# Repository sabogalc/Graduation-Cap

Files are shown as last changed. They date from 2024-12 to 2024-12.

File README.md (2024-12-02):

# Graduation Cap
This is a PCB that I made to sit on top of my graduation cap for my bachelor's in electrical engineering. The board is designed around the 9.5x9.5" Herff Jones caps used at UF, but it could easily be adapted for other caps. This board is capable of playing three different `.WAV` music files, and I have populated mine with three Florida Gators fight songs. There is also an LED sequence that cycles through each light on the cap while displaying a message on the OLED display.

> Graduation Cap
> Side-by-side of the PCB render in KiCad and the board on my cap in real life.

# Project Inspirations

While I have had this project on my mind for a few years now, there are some people that have made similar projects, and I modeled some of my work off of theirs.

1. [LED Graduation Cap](https://github.com/matthewScohen/LED_Graduation_Cap) by Matthew Cohen

2. [Graduation Cap](https://github.com/miekush/graduation-cap) by Mike Kushnerik

Notably, Mike's project has accommodations for the tassel, which I overlooked and ended up just hot gluing onto my cap. The PCB itself is also hot glued at each of the cap's four corners.

# Code

The program to run this board is included in this repository as `main.py`, and it was designed around a Raspberry Pi Pico running MicroPython (yes, I know C would have run better, no I am not good at writing code). You will need the following driver files saved to the Pico in order for the code to run.

1. [sdcard.py](https://github.com/micropython/micropython-lib/blob/master/micropython/drivers/storage/sdcard/sdcard.py) from [micropython-lib](https://github.com/micropython/micropython-lib)

2. [sh1106.py](https://github.com/raspberrypi/pico-micropython-examples/blob/master/i2c/1106oled/sh1106.py) from [Pico MicroPython Examples](https://github.com/raspberrypi/pico-micropython-examples)

3. [tlc5940.py](https://github.com/sabogalc/tlc5940-micropython/blob/master/tlc5940.py) from [TLC5940 MicroPython Library](https://github.com/oysols/tlc5940-micropython)**

** **Please note that the code does not currently work on the Pico. I have linked to my fork of the driver which does work on the Pico and has been submitted as a pull request.**

4. [wavplayer.py](https://github.com/miketeachman/micropython-i2s-examples/blob/master/examples/wavplayer.py) from [MicroPython I2S Examples](https://github.com/miketeachman/micropython-i2s-examples)

# Ordering Parts

I have included BOMs for both DigiKey and Mouser to obtain the parts for this board, but the Mouser BOM is missing the socket headers since I could not find any on there. The board will still work with the components directly soldered down, but I liked the flexibility the sockets offered, especially while debugging. One component that will be needed to be purchased externally is the I2C OLED, and I got mine [on Amazon](https://www.amazon.com/dp/B07BHHV844).

# Notes

I wanted to have a mode where all the lights could come on at once, but I was unable to accomplish this without prominent flickering. I believe this may be due to differences in the forward voltages of the blue and orange LEDs, as the flicker does not occur when only lighting multiple LEDs of one color (side note, the blue LED was [partially invented at UF](https://www.nobelprize.org/prizes/physics/2014/nakamura/biographical/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.)!). If anyone has more information on this, please feel free to share it.

Another thing to note is that I had to cut a hole in my cap so that the battery leads were accessible, but if you wanted to power the board with a USB cable and a power bank that should work as well.

While the board is personalized to me and my graduation year, it can be modified to any year, school, or person. Of course, most of the fun in making something like this is in designing it yourself, so feel free to use this project in part or in whole to help move your project along.

> Graduation Picture
> Me with my graduation cap outside of UF's New Engineering Building (it's not that new but the name has stuck).

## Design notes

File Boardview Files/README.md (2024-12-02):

# Boardview Files

## What is a Boardview File?

A boardview file is a netlist of all the connections on a PCB with every component laid out exactly as it is in real life. This modern approach provides a more intuitive way to inspect connections and troubleshoot PCBs compared to traditional schematic diagrams.

## How Can I View These Files?

Much like how there are many PCB EDA software programs out there, there are also many board viewing programs. The two that I have used and recommend are listed below:

1. **[OpenBoardView](https://github.com/OpenBoardView/OpenBoardView)**  
   - **License:** MIT  
   - **Description:** An open-source tool for viewing boardview files. It provides essential features for inspecting PCB layouts.

2. **[FlexBV](https://pldaniels.com/flexbv/)**  
   - **License:** Commercial (free version available)  
   - **Description:** A commercial tool with advanced features for viewing and analyzing boardview files. The free version offers most of the basic functionalities.

### Example View

Below is a screenshot of my graduation cap PCB as viewed in FlexBV:

Graduation Cap PCB Boardview

In this view, you can observe the following:
- **Net Highlighting:** The +3V3 net is highlighted in green across the board.
- **Component Table:** A table on the right lists components and their pin numbers associated with +3V3.
- **Designator Information:** The designators, values of resistors and capacitors, and component footprints are all displayed.

### Note on Metadata

The metadata you see (e.g., component values, designators) is stored in the `.obdata` file. As of December 2024, this metadata is viewable only in FlexBV. The `.obdata` format is [open and documented](https://openboarddata.org/), and I would very much like to see the feature added to OpenBoardView.

### How Can I Create Boardview Files for My Own Designs?

All of the boardview files I make for my projects are using [an open-source KiCad plugin](https://github.com/whitequark/kicad-boardview). When I first came across this plugin, it had a few bugs with current versions of KiCad, so I submitted some pull requests and the plugin is back into perfect operating condition. The `.obdata` generation script is currently internal since I made a bit of a mess [submitting that PR](https://github.com/whitequark/kicad-boardview/pull/16), but I am looking to release it eventually.

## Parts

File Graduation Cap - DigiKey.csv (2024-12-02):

Index | Quantity | Part Number | Manufacturer Part Number | Description | Customer Reference | Available | Backorder | Unit Price | Extended Price USD
1 | 4 | 1276-1946-1-ND | CL10B105KP8NNNC | CAP CER 1UF 10V X7R 0603 |  | 4 | 0 | 0.08 | 0.32
2 | 1 | 1276-1009-1-ND | CL10B103KB8NNNC | CAP CER 10000PF 50V X7R 0603 |  | 1 | 0 | 0.08 | 0.08
3 | 3 | P1.00KHCT-ND | ERJ-3EKF1001V | RES SMD 1K OHM 1% 1/10W 0603 |  | 3 | 0 | 0.1 | 0.3
4 | 2 | P2.00KHCT-ND | ERJ-3EKF2001V | RES SMD 2K OHM 1% 1/10W 0603 |  | 2 | 0 | 0.1 | 0.2
5 | 20 | SLI-343D8U3F-ND | SLI-343D8U3F | LED ORANGE DIFFUSED T-1 T/H |  | 20 | 0 | 0.302 | 6.04
6 | 18 | 732-5015-ND | 151051BS04000 | LED BLUE DIFFUSED 5MM ROUND T/H |  | 18 | 0 | 0.24 | 4.32
7 | 1 | 296-35975-1-ND | TLC5940PWPR | IC LED DRVR LIN 120MA 28HTSSOP |  | 1 | 0 | 3 | 3
8 | 1 | MCP73812T-420I/OTCT-ND | MCP73812T-420I/OT | IC BATT CNTL LI-ION 1CEL SOT23-5 |  | 1 | 0 | 0.73 | 0.73
9 | 1 | TC2015-3.3VCTCT-ND | TC2015-3.3VCTTR | IC REG LINEAR 3.3V 100MA SOT23-5 |  | 1 | 0 | 0.56 | 0.56
10 | 4 | CKN10880CT-ND | PTS645SL43SMTR92 LFS | SWITCH TACTILE SPST-NO 0.05A 12V |  | 4 | 0 | 0.4 | 1.6
11 | 3 | IRF9540NSTRLPBFCT-ND | IRF9540NSTRLPBF | MOSFET P-CH 100V 23A D2PAK |  | 3 | 0 | 2.72 | 8.16
12 | 2 | S7018-ND | PPTC201LFBN-RC | CONN HDR 20POS 0.1 TIN PCB |  | 2 | 0 | 1.1 | 2.2
13 | 1 | 2648-SC0917-ND | SC0917 | RASPBERRY PI PICO H RP2040 |  | 1 | 0 | 5 | 5
14 | 1 | S7002-ND | PPTC041LFBN-RC | CONN HDR 4POS 0.1 TIN PCB |  | 1 | 0 | 0.4 | 0.4
15 | 1 | S7005-ND | PPTC071LFBN-RC | CONN HDR 7POS 0.1 TIN PCB |  | 1 | 0 | 0.51 | 0.51
16 | 1 | 1528-1696-ND | 3006 | EVAL BOARD FOR MAX98357A |  | 1 | 0 | 5.95 | 5.95
17 | 1 | 102-1560-ND | CLS0401MAE-L152 | SPEAKER 4OHM 1W TOP PORT 91DB |  | 1 | 0 | 4.58 | 4.58
18 | 1 | S7007-ND | PPTC091LFBN-RC | CONN HDR 9POS 0.1 TIN PCB |  | 1 | 0 | 0.61 | 0.61
19 | 1 | 1528-4682-ND | 4682 | MICROSD SPI/SPIO BREAKOUT BOARD |  | 1 | 0 | 3.5 | 3.5
20 | 1 | 455-1719-ND | S2B-PH-K-S | CONN HEADER R/A 2POS 2MM |  | 1 | 0 | 0.1 | 0.1
21 | 1 | 1528-1838-ND | 258 | BATTERY LITH-ION 3.7V 1.2AH |  | 1 | 0 | 9.95 | 9.95

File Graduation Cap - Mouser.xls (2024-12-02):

SHOPPING CART
This is not an invoice
02-Dec-24 03:36:52
 | Mouser # | Mfr. # | Manufacturer | Customer # | Description | RoHS | Lifecycle | Order Qty. | Price (USD) | Ext.: (USD)
1 | 187-CL10B105KP8NNNC | CL10B105KP8NNNC | Samsung Electro-Mechanics |  | Multilayer Ceramic Capacitors MLCC - SMD/SMT 1uF+/-10% 10V X7R 16 0603 | RoHS Compliant |  | 4 | $0.10 | $0.40
2 | 187-CL10B103KB8NNNC | CL10B103KB8NNNC | Samsung Electro-Mechanics |  | Multilayer Ceramic Capacitors MLCC - SMD/SMT SAMSUNG | RoHS Compliant |  | 1 | $0.10 | $0.10
3 | 667-ERJ-3EKF1001V | ERJ-3EKF1001V | Panasonic |  | Thick Film Resistors - SMD 0603 1Kohms 1% AEC-Q200 | RoHS Compliant By Exemption |  | 3 | $0.10 | $0.30
4 | 667-ERJ-3EKF2001V | ERJ-3EKF2001V | Panasonic |  | Thick Film Resistors - SMD 0603 2Kohms 1% AEC-Q200 | RoHS Compliant By Exemption |  | 2 | $0.10 | $0.20
5 | 755-SLI-343D8U3F | SLI-343D8U3F | ROHM Semiconductor |  | Standard LEDs - Through Hole ORANGE-DIFF COLORED 40 VIEW ANGLE 611NM | RoHS Compliant |  | 20 | $0.299 | $5.98
6 | 710-151051BS04000 | 151051BS04000 | Wurth Elektronik |  | Standard LEDs - Through Hole WL-TMRC THT Mono Diffused Rnd5mm Blue | RoHS Compliant |  | 18 | $0.26 | $4.68
7 | 595-TLC5940PWPR | TLC5940PWPR | Texas Instruments |  | LED Lighting Drivers 4096 Step Grayscale LED Driver | RoHS Compliant |  | 1 | $3.00 | $3.00
8 | 579-MCP73812T-420IOT | MCP73812T-420I/OT | Microchip |  | Battery Management Simple Integr Li-Ion /Li-Poly Chrg | RoHS Compliant |  | 1 | $0.68 | $0.68
9 | 579-TC2015-3.3VCTTR | TC2015-3.3VCTTR | Microchip |  | LDO Voltage Regulators .1mA w/Shtdn & Ref B 3.3V | RoHS Compliant |  | 1 | $0.50 | $0.50
10 | 611-PTS645SL43SMTR92 | PTS645SL43SMTR92LFS | C&K Switches |  | Tactile Switches SWITCH TACTILE | RoHS Compliant | Factory Special Order | 4 | $0.21 | $0.84
11 | 942-IRF9540NSTRLPBF | IRF9540NSTRLPBF | Infineon |  | MOSFETs MOSFT PCh -100V -23A 117mOhm 64.7nC |  |  | 3 | $2.29 | $6.87
12 | 358-SC0917 | SC0917 | Raspberry Pi |  | Single Board Computers Raspberry Pi Pico H | RoHS Compliant |  | 1 | $5.00 | $5.00
13 | 485-3006 | 3006 | Adafruit |  | Amplifier IC Development Tools I2S 3W Class D Amp Breakout MAX98357A | RoHS Compliant |  | 1 | $5.95 | $5.95
14 | 490-CLS0401MAE-L152 | CLS0401MAE-L152 | Same Sky |  | Speakers & Transducers Speakers | RoHS Compliant |  | 1 | $4.12 | $4.12
15 | 485-4682 | 4682 | Adafruit |  | Memory IC Development Tools Adafruit Micro SD SPI or SDIO Card Breakout Board - 3V ONLY! | RoHS Compliant |  | 1 | $3.50 | $3.50
16 | 306-S2BPHKSLFSNPP | S2B-PH-K-S(LF)(SN)(PP) | JST |  | JST Automotive Connectors PH HEADER (SIDE) | RoHS Compliant | New At Mouser | 1 | $0.18 | $0.18
17 | 485-258 | 258 | Adafruit |  | Adafruit Accessories Lithium Ion Polymer Battery 3.7V 1200mAh | RoHS Compliant |  | 1 | $9.95 | $9.95
By submitting your order you agree to these terms and conditions. (https://www.mouser.com/saleterms) |  |  |  |  |  |  |  |  | Merchandise: | $52.25
Prices are reflected at the date and time shown. |  |  |  |  |  |  |  |  | Shipping Charge: | $7.99
 |  |  |  |  |  |  |  |  | Backorder Shipping: | $1.99

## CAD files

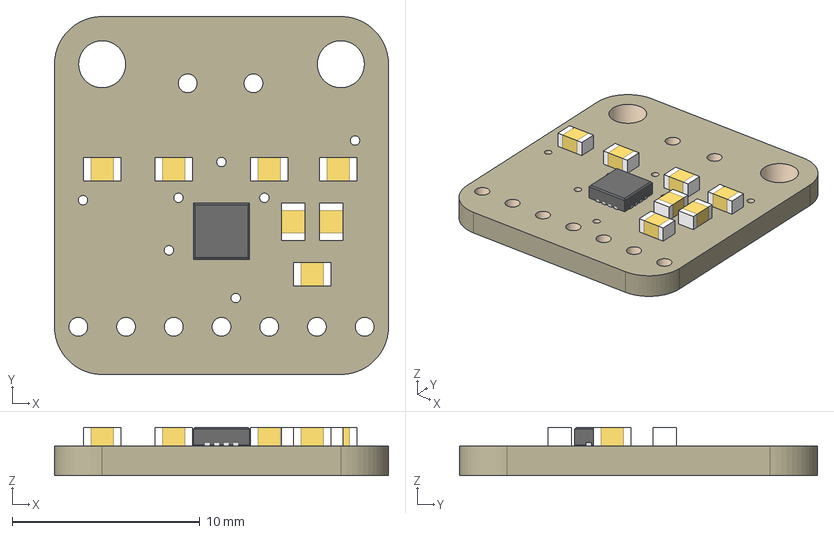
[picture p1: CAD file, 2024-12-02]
STEP Files/3006 MAX98357.step
17.8 x 19.1 x 2.57 mm
Board
MAX98357A
220pF x 7

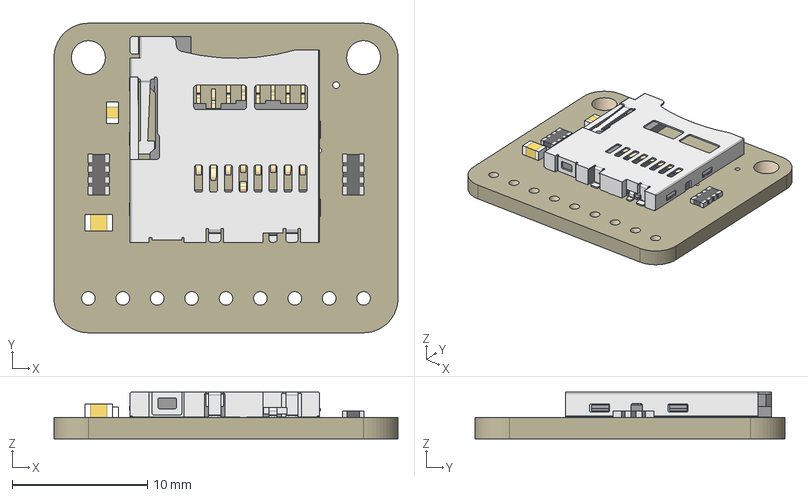
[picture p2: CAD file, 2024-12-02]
STEP Files/4682 Micro SD Breakout.step
25.4 x 22.9 x 3.45 mm
Board
microSD
10uF
0.1uF
47K x 2

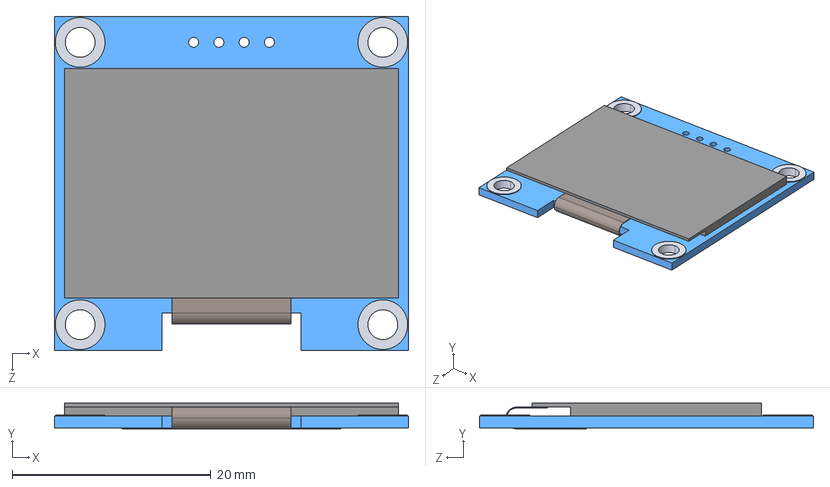
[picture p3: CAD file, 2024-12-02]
STEP Files/I2C SSH1106 OLED.STEP
35.6 x 2.60 x 33.6 mm

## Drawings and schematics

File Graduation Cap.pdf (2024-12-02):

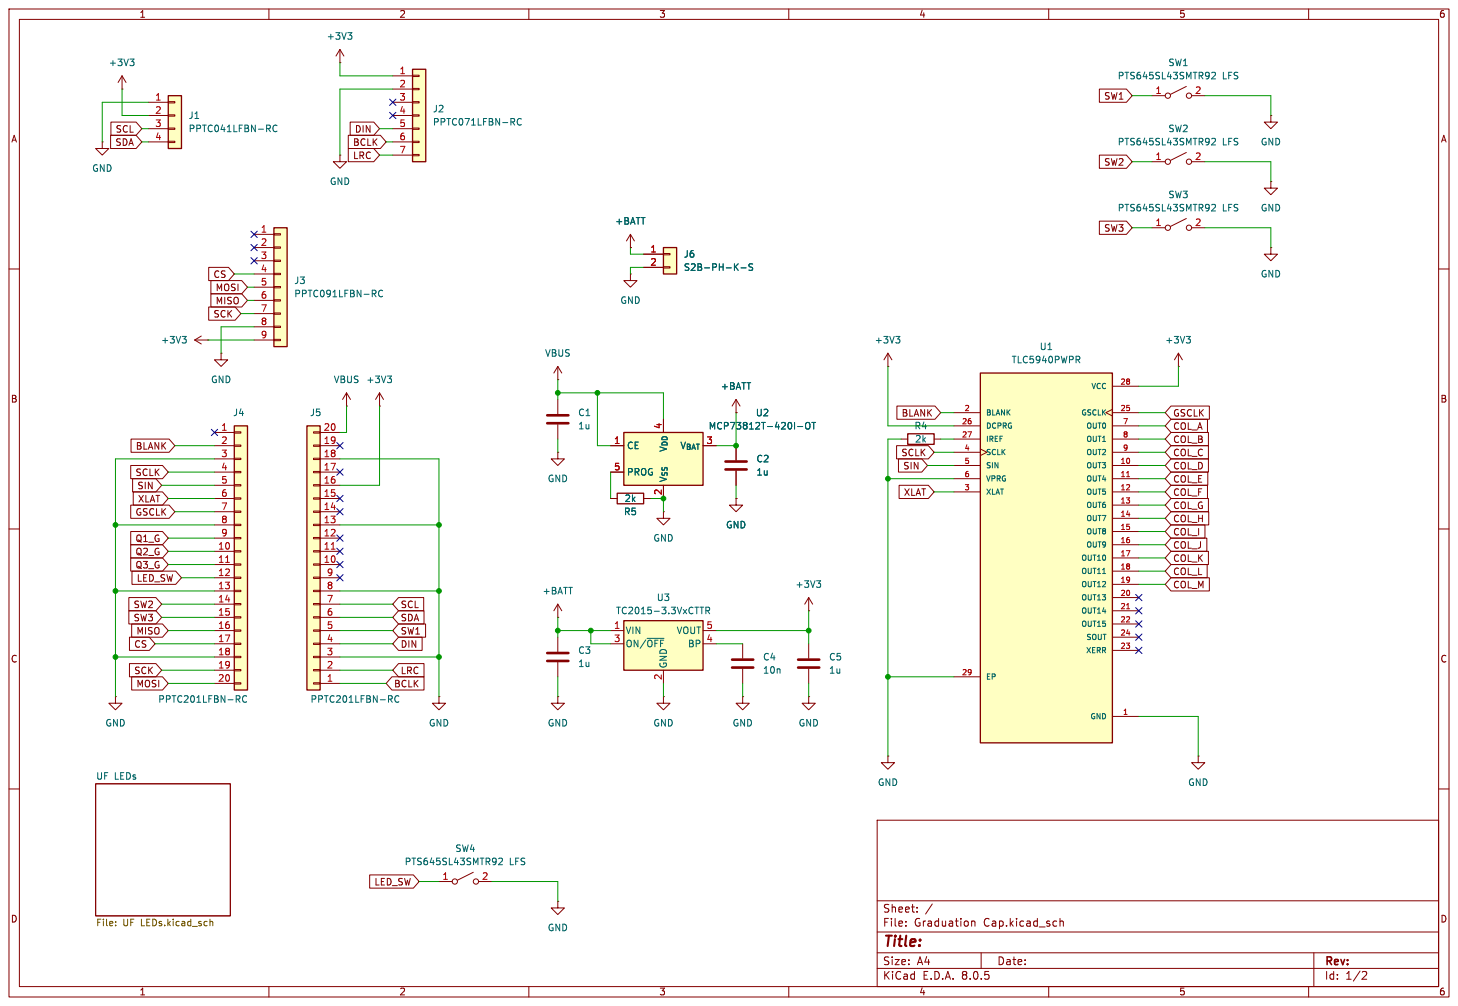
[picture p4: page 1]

2 ON/~{OFF} 3 BP 4 VOUT 5 U3 TC2015-3.3VxCTTR GSCLK MISO

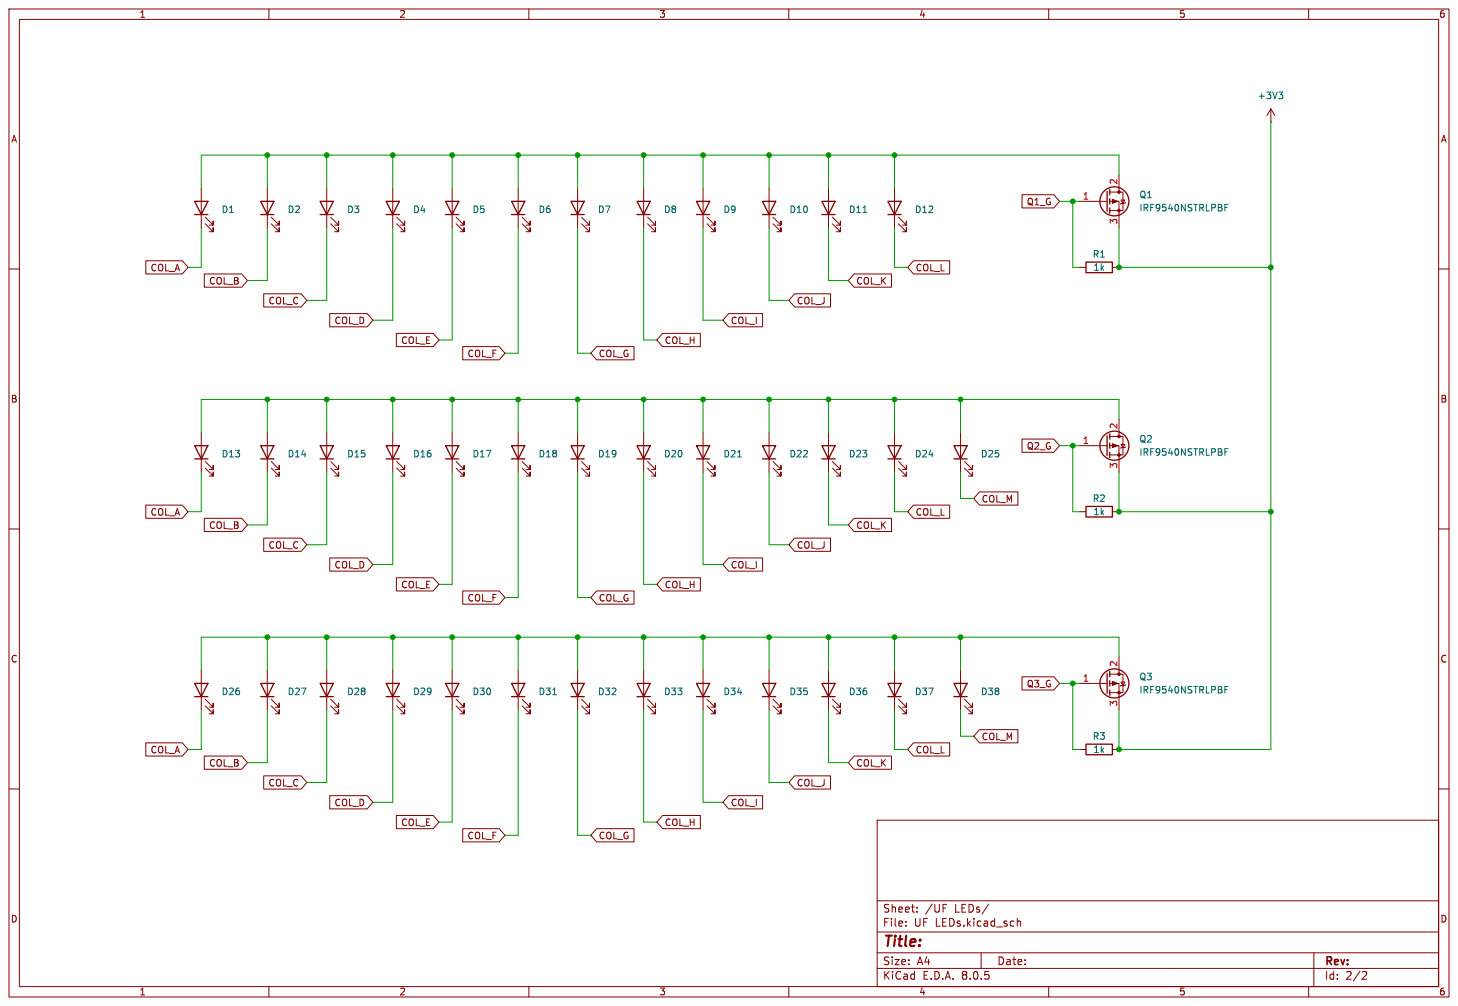
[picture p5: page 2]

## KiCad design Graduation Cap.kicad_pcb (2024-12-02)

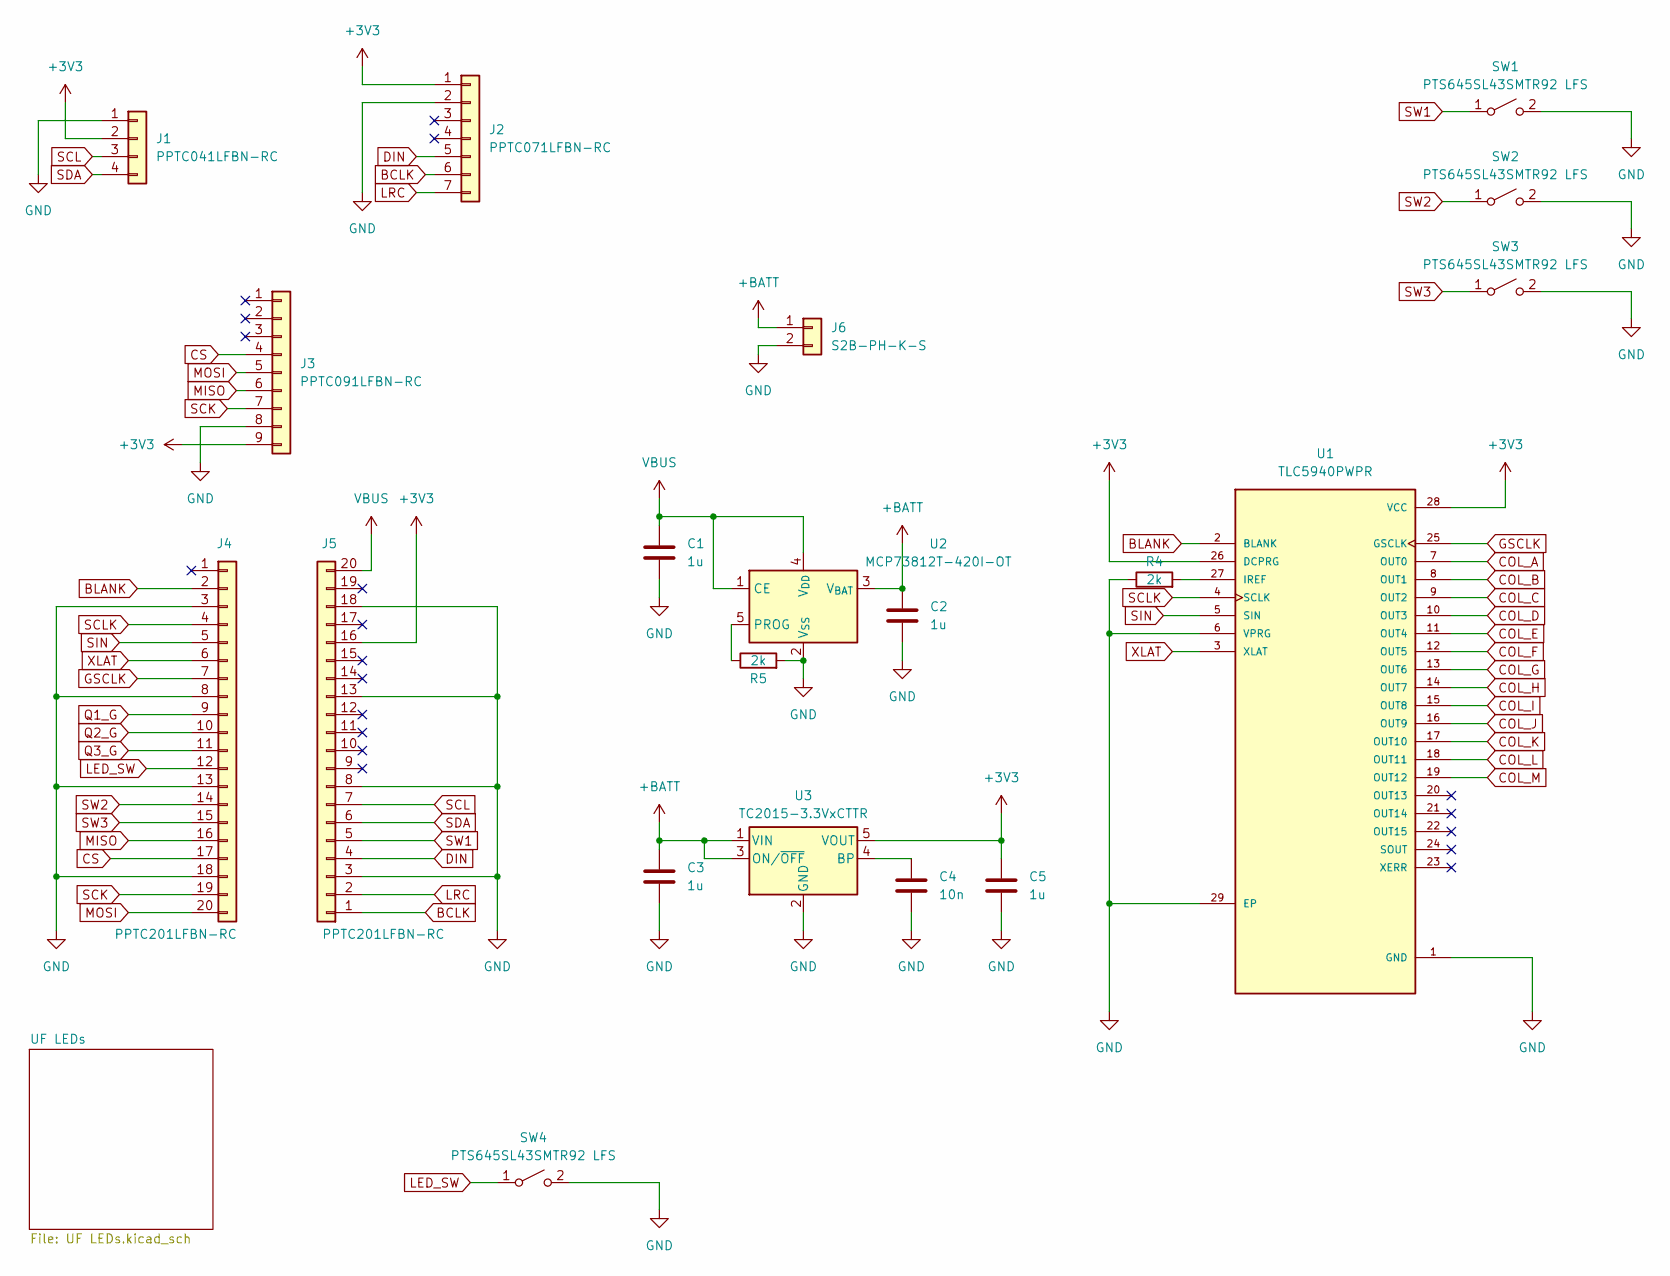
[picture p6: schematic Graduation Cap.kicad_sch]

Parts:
C1, C2, C3, C5: 1u; C_0603_1608Metric
C4: 10n; C_0603_1608Metric
J1: PPTC041LFBN-RC; PinSocket_1x04_P2.54mm_Vertical
J2: PPTC071LFBN-RC; PinSocket_1x07_P2.54mm_Vertical
J3: PPTC091LFBN-RC; PinSocket_1x09_P2.54mm_Vertical
J4, J5: PPTC201LFBN-RC; PinSocket_1x20_P2.54mm_Vertical
J6: S2B-PH-K-S; JST_PH_S2B-PH-K_1x02_P2.00mm_Horizontal
R4, R5: 2k; R_0603_1608Metric
SW1, SW2, SW3, SW4: PTS645SL43SMTR92 LFS; SW_SPST_PTS645
U1: TLC5940PWPR; HTSSOP-28-1EP_4.4x9.7mm_P0.65mm_EP3.4x9.5mm_Mask2.4x6.17mm_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
U2: MCP73812T-420I-OT; SOT-23-5
U3: TC2015-3.3VxCTTR; SOT-23-5

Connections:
+3V3: C5.1, J1.2, J2.1, J3.9, J5.16, U1.26 (DCPRG), U1.28 (VCC), U3.5 (VOUT); also elsewhere on the board
+BATT: C2.1, C3.1, J6.1, U2.3 (V_{BAT}), U3.1 (VIN), U3.3 (ON/~OFF)
BCLK: J2.6, J5.1
BLANK: J4.2, U1.2 (BLANK)
COL_A: U1.7 (OUT0); also elsewhere on the board
COL_B: U1.8 (OUT1); also elsewhere on the board
COL_C: U1.9 (OUT2); also elsewhere on the board
COL_D: U1.10 (OUT3); also elsewhere on the board
COL_E: U1.11 (OUT4); also elsewhere on the board
COL_F: U1.12 (OUT5); also elsewhere on the board
COL_G: U1.13 (OUT6); also elsewhere on the board
COL_H: U1.14 (OUT7); also elsewhere on the board
COL_I: U1.15 (OUT8); also elsewhere on the board
COL_J: U1.16 (OUT9); also elsewhere on the board
COL_K: U1.17 (OUT10); also elsewhere on the board
COL_L: U1.18 (OUT11); also elsewhere on the board
COL_M: U1.19 (OUT12); also elsewhere on the board
CS: J3.4, J4.17
DIN: J2.5, J5.4
GND: C1.2, C2.2, C3.2, C4.2, C5.2, J1.1, J2.2, J3.8, J4.3, J4.8, J4.13, J4.18, J5.3, J5.8, J5.13, J5.18, J6.2, R4.1, R5.2, SW1.2 (B), SW2.2 (B), SW3.2 (B), SW4.2 (B), U1.1 (GND), U1.6 (VPRG), U1.29 (EP), U2.2 (V_{SS}), U3.2 (GND)
GSCLK: J4.7, U1.25 (GSCLK)
LED_SW: J4.12, SW4.1 (A)
LRC: J2.7, J5.2
MISO: J3.6, J4.16
MOSI: J3.5, J4.20
unnamed: R4.2, U1.27 (IREF)
unnamed: R5.1, U2.5 (PROG)
unnamed: C4.1, U3.4 (BP)
Q1_G: J4.9; also elsewhere on the board
Q2_G: J4.10; also elsewhere on the board
Q3_G: J4.11; also elsewhere on the board
SCK: J3.7, J4.19
SCL: J1.3, J5.7
SCLK: J4.4, U1.4 (SCLK)
SDA: J1.4, J5.6
SIN: J4.5, U1.5 (SIN)
SW1: J5.5, SW1.1 (A)
SW2: J4.14, SW2.1 (A)
SW3: J4.15, SW3.1 (A)
VBUS: C1.1, J5.20, U2.1 (CE), U2.4 (V_{DD})
XLAT: J4.6, U1.3 (XLAT)

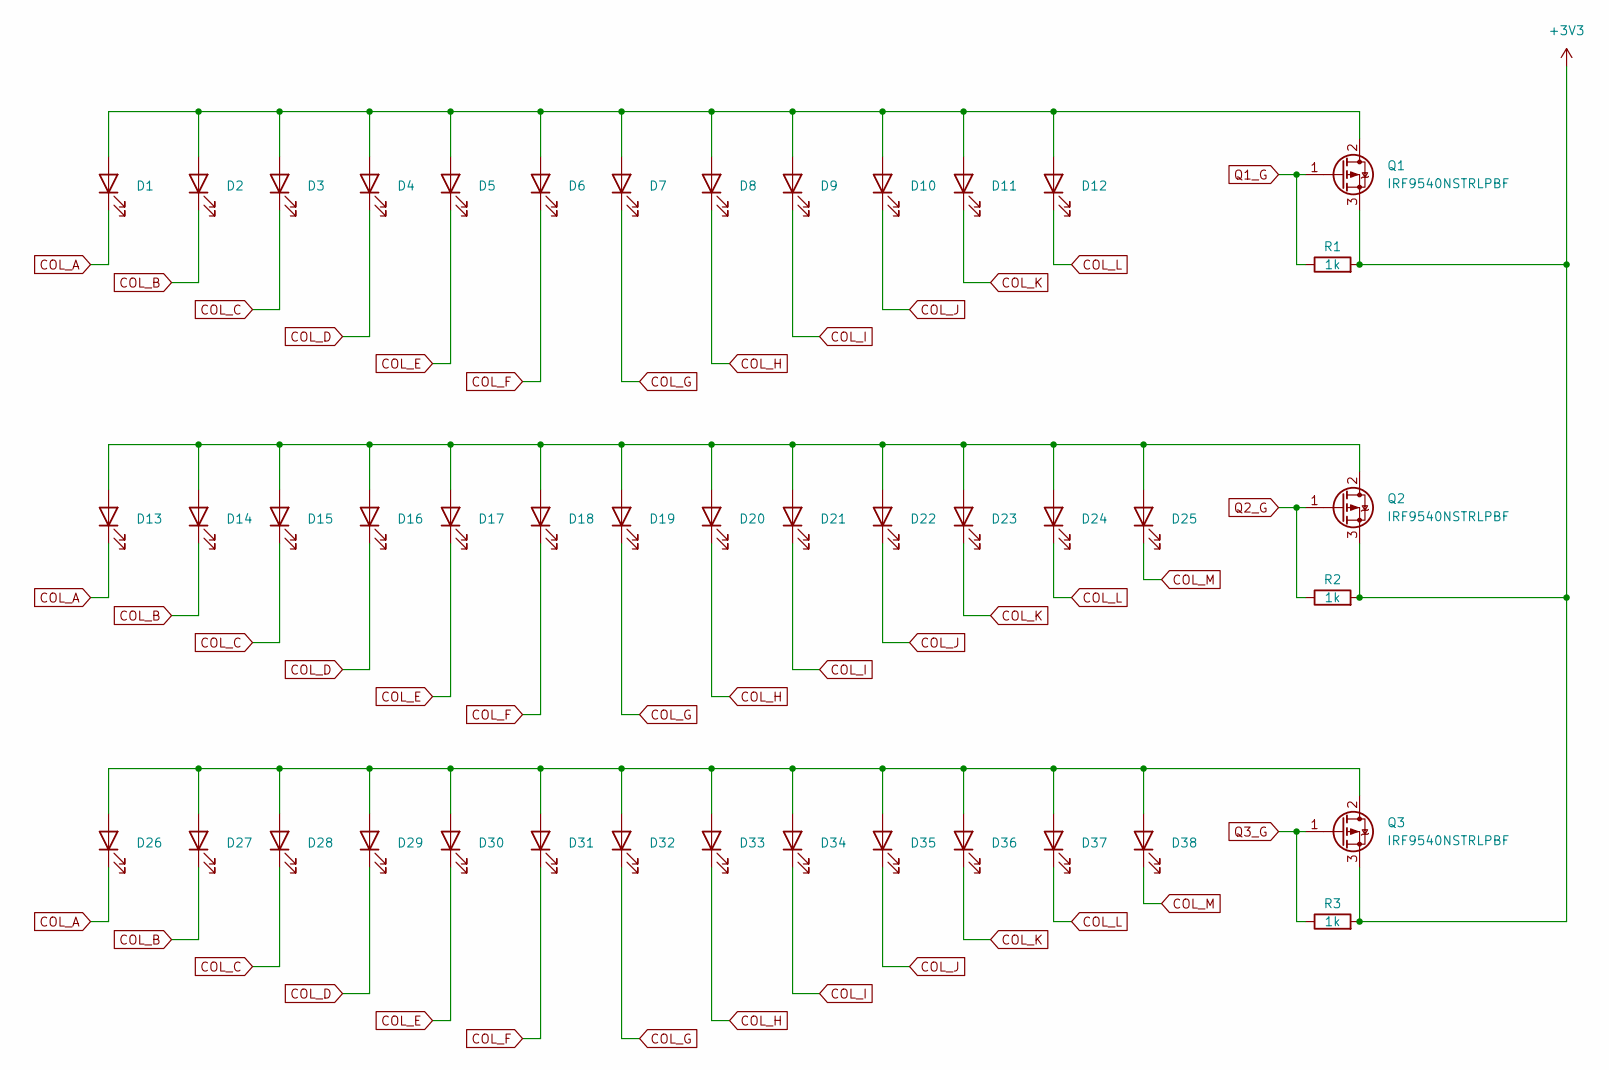
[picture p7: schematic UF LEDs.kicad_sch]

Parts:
D1, D2, D3, D4, D5, D6, D7, D8, D9, D10, D11, D12, D13, D14, D15, D16, D17, D18: 151051BS04000; BLUE-LED-5MM-ROUND
D19, D20, D21, D22, D23, D24, D25, D26, D27, D28, D29, D30, D31, D32, D33, D34, D35, D36, D37, D38: SLI-343D8U3F; ORANGE-LED-5MM-ROUND
Q1, Q2, Q3: IRF9540NSTRLPBF; TO-263-2
R1, R2, R3: 1k; R_0603_1608Metric

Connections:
+3V3: Q1.3 (S), Q2.3 (S), Q3.3 (S), R1.2, R2.2, R3.2; also elsewhere on the board
COL_A: D1.1 (K), D13.1 (K), D26.1 (K); also elsewhere on the board
COL_B: D2.1 (K), D14.1 (K), D27.1 (K); also elsewhere on the board
COL_C: D3.1 (K), D15.1 (K), D28.1 (K); also elsewhere on the board
COL_D: D4.1 (K), D16.1 (K), D29.1 (K); also elsewhere on the board
COL_E: D5.1 (K), D17.1 (K), D30.1 (K); also elsewhere on the board
COL_F: D6.1 (K), D18.1 (K), D31.1 (K); also elsewhere on the board
COL_G: D7.1 (K), D19.1 (K), D32.1 (K); also elsewhere on the board
COL_H: D8.1 (K), D20.1 (K), D33.1 (K); also elsewhere on the board
COL_I: D9.1 (K), D21.1 (K), D34.1 (K); also elsewhere on the board
COL_J: D10.1 (K), D22.1 (K), D35.1 (K); also elsewhere on the board
COL_K: D11.1 (K), D23.1 (K), D36.1 (K); also elsewhere on the board
COL_L: D12.1 (K), D24.1 (K), D37.1 (K); also elsewhere on the board
COL_M: D25.1 (K), D38.1 (K); also elsewhere on the board
unnamed: D1.2 (A), D2.2 (A), D3.2 (A), D4.2 (A), D5.2 (A), D6.2 (A), D7.2 (A), D8.2 (A), D9.2 (A), D10.2 (A), D11.2 (A), D12.2 (A), Q1.2 (D)
unnamed: D13.2 (A), D14.2 (A), D15.2 (A), D16.2 (A), D17.2 (A), D18.2 (A), D19.2 (A), D20.2 (A), D21.2 (A), D22.2 (A), D23.2 (A), D24.2 (A), D25.2 (A), Q2.2 (D)
unnamed: D26.2 (A), D27.2 (A), D28.2 (A), D29.2 (A), D30.2 (A), D31.2 (A), D32.2 (A), D33.2 (A), D34.2 (A), D35.2 (A), D36.2 (A), D37.2 (A), D38.2 (A), Q3.2 (D)
Q1_G: Q1.1 (G), R1.1; also elsewhere on the board
Q2_G: Q2.1 (G), R2.1; also elsewhere on the board
Q3_G: Q3.1 (G), R3.1; also elsewhere on the board

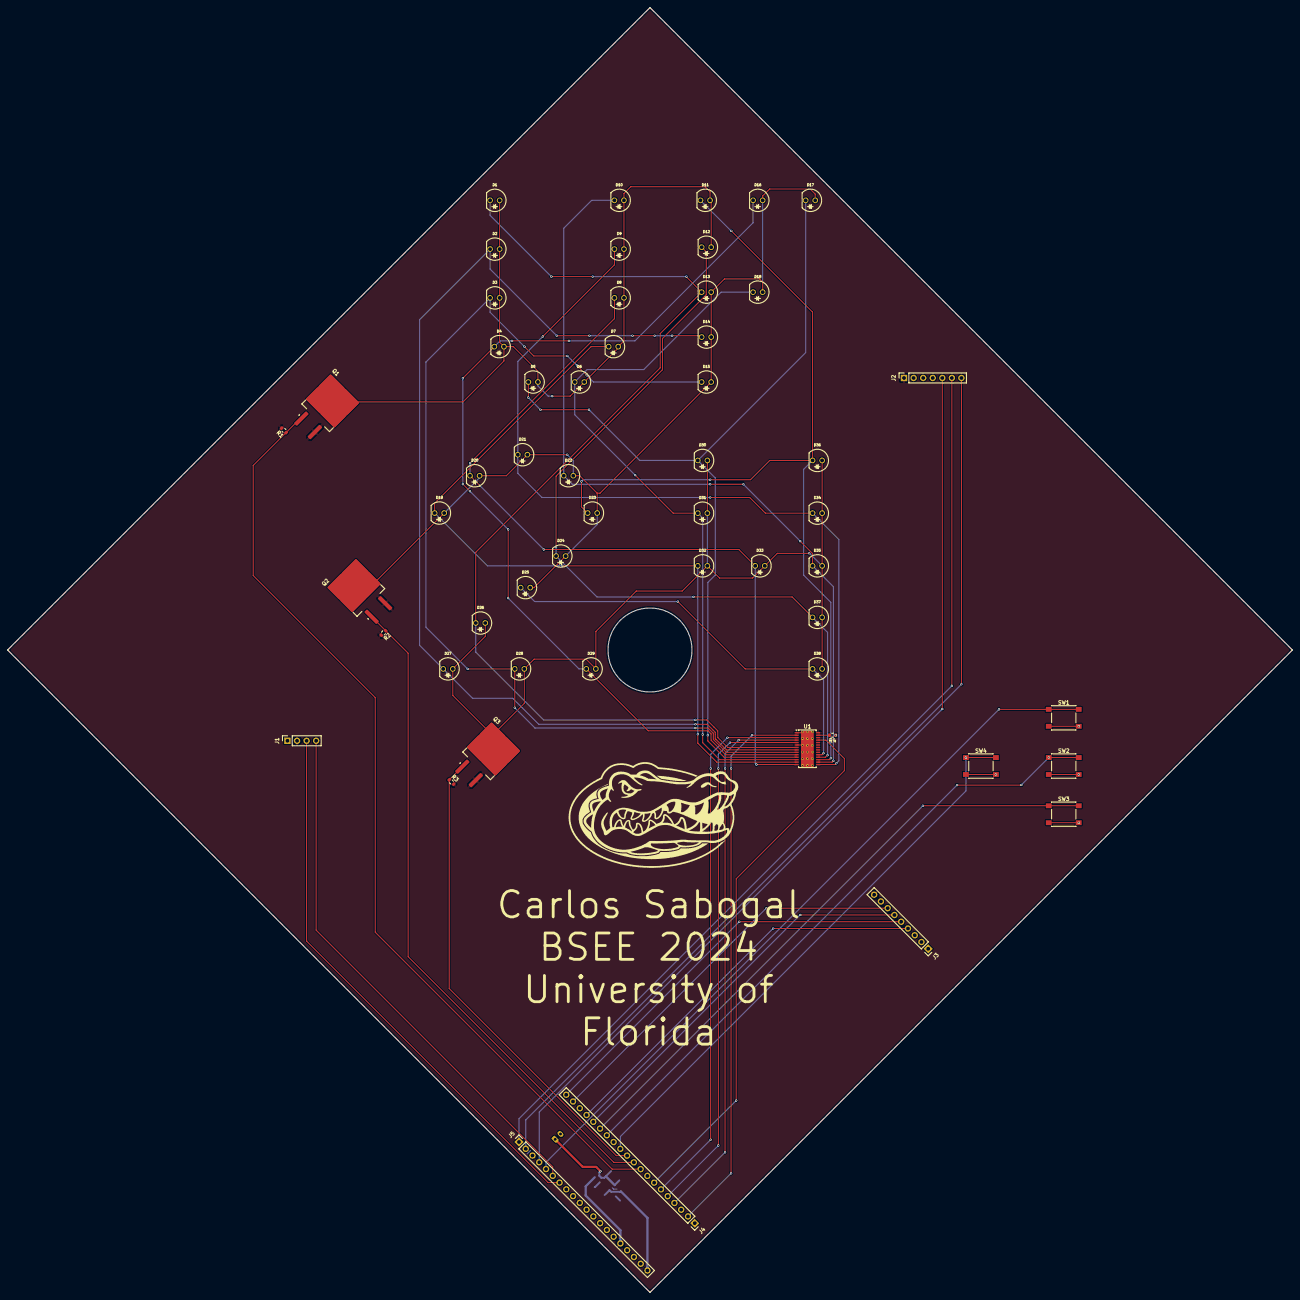
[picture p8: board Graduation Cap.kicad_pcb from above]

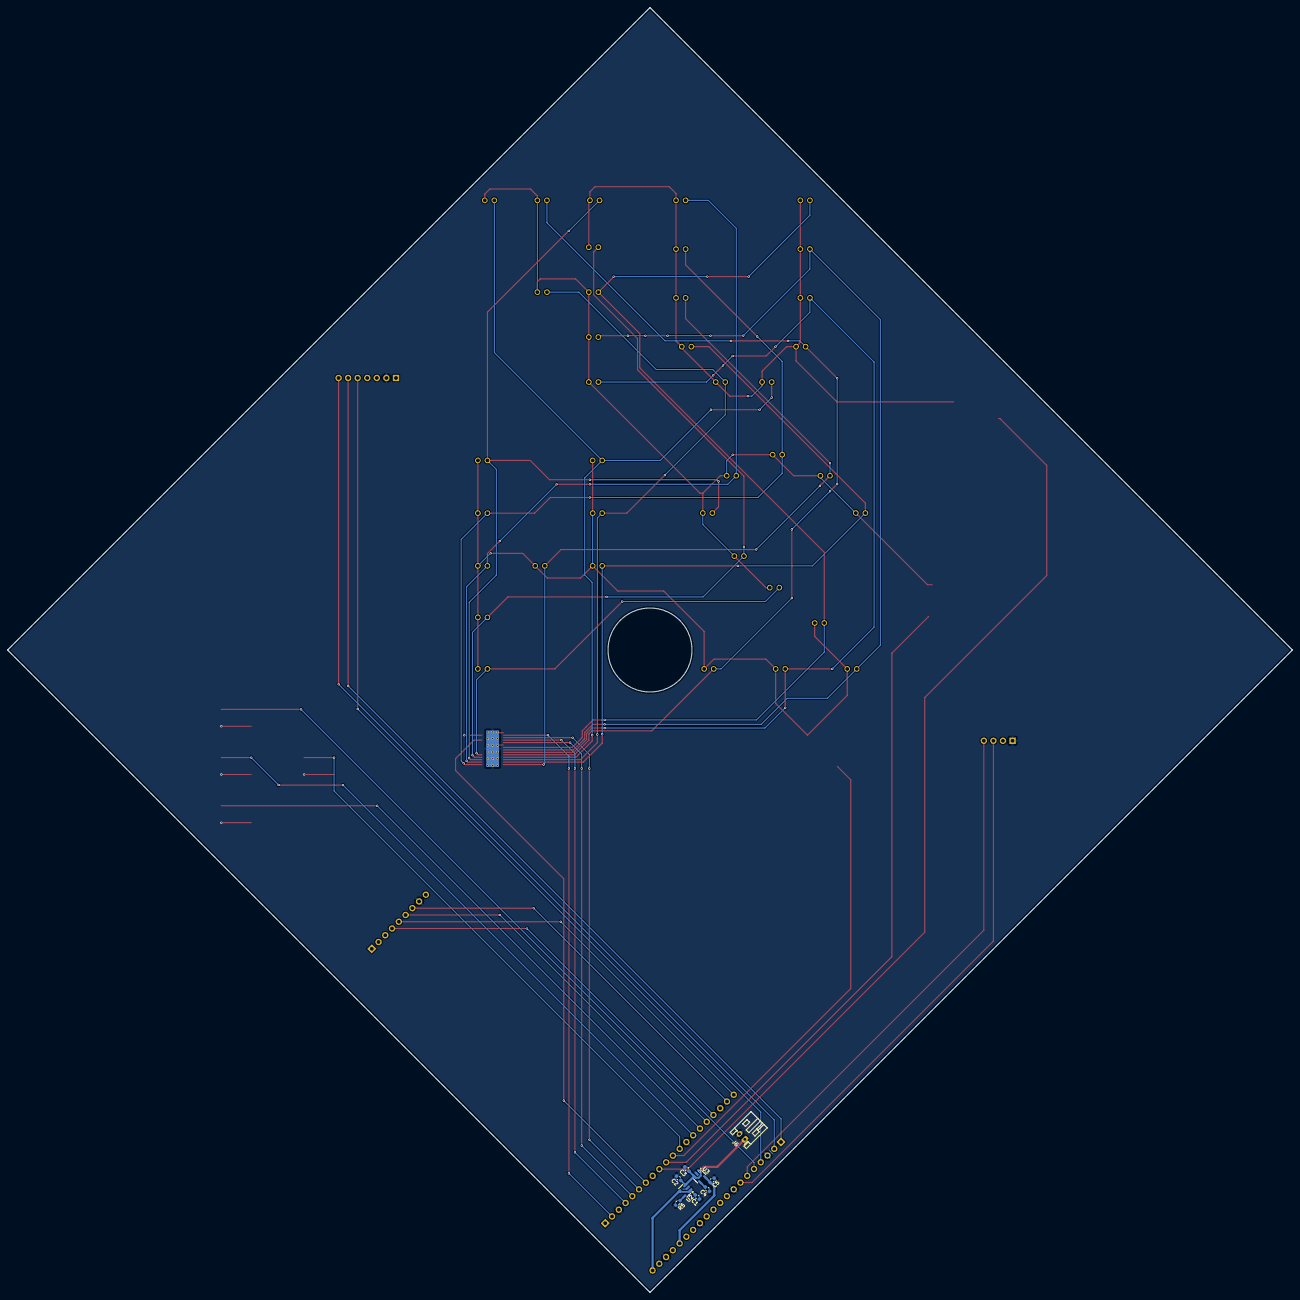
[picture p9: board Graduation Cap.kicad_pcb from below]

Board: 2 copper layers, 341.2 x 341.2 mm, 64 parts (9 on the bottom side), 44 nets.

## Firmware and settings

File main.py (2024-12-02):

import os
import time
from machine import I2C, Pin, SPI
from sh1106 import SH1106_I2C
from wavplayer import WavPlayer
from sdcard import SDCard
from tlc5940 import interface, simple_byte_array

# TLC5940 GPIO pin definitions
GSCLK_PIN = 5
BLANK_PIN = 1
VPRG_PIN = 0
XLAT_PIN = 4
SCLK_PIN = 2
SIN_PIN = 3

# PMOS gate pins
PMOS_ROW1_PIN = 7
PMOS_ROW2_PIN = 6
PMOS_ROW3_PIN = 8

# Initialize the TLC5940 interface
tlc = interface(GSCLK_PIN, BLANK_PIN, VPRG_PIN, XLAT_PIN, SCLK_PIN, SIN_PIN)

# Configure PMOS pins
pmos_row1 = Pin(PMOS_ROW1_PIN, Pin.OUT)
pmos_row2 = Pin(PMOS_ROW2_PIN, Pin.OUT)
pmos_row3 = Pin(PMOS_ROW3_PIN, Pin.OUT)

# Initialize PMOS gates (turn off all rows initially)
pmos_row1.value(0)
pmos_row2.value(0)
pmos_row3.value(0)

# Initialize I2C for OLED display
i2c = I2C(0, scl=Pin(21), sda=Pin(20), freq=200000)
oled = SH1106_I2C(128, 64, i2c)
oled.rotate(1)

# Initialize SPI for SD Card
cs = Pin(13, Pin.OUT)
spi = SPI(1, baudrate=1_000_000, polarity=0, phase=0, bits=8,
          firstbit=SPI.MSB, sck=Pin(14), mosi=Pin(15), miso=Pin(12))

sd = SDCard(spi, cs)
sd.init_spi(25_000_000)
os.mount(sd, "/sd")

SCK_PIN = 16
WS_PIN = 17
SD_PIN = 18
I2S_ID = 0
BUFFER_LENGTH_IN_BYTES = 40000

# Define buttons
Button_1 = Pin(19, Pin.IN, Pin.PULL_UP)
Button_2 = Pin(10, Pin.IN, Pin.PULL_UP)
Button_3 = Pin(11, Pin.IN, Pin.PULL_UP)
Button_4 = Pin(9, Pin.IN, Pin.PULL_UP)  # Used for toggling LED sequence

# Map buttons to songs
button_songs = {
    Button_1: "The Orange And Blue.wav",
    Button_2: "We Are The Boys Of Old Florida.wav",
    Button_3: "Jaws Go Gators.wav"
}

# Initialize WavPlayer
wp = WavPlayer(
    id=I2S_ID,
    sck_pin=Pin(SCK_PIN),
    ws_pin=Pin(WS_PIN),
    sd_pin=Pin(SD_PIN),
    ibuf=BUFFER_LENGTH_IN_BYTES,
)

# Variables for LED cycling
cycling = False
led_index = 0
last_led_update = time.ticks_ms()
last_button_press = 0
debounce_delay = 200  # in milliseconds
led_update_interval = 100  # in milliseconds

# Variables for the "Go Gators!" display effect
go_gators_text = "Go Gators!"
text_x_offset = -75  # Start from left off-screen
text_scroll_speed = 2
text_last_update = time.ticks_ms()
text_update_interval = 50  # in milliseconds
text_paused = False
text_pause_start = 0
text_pause_duration = 5000  # (5 seconds)

def turn_on_leds(index):
    """
    Turn on LEDs in sequence based on the current index.
    """
    outputs = ['0'] * 16  # Initialize all outputs to '0'
    channel = index % 13   # Channels 0-12 for all rows

    # Activate the appropriate PMOS for the row
    if index < 13:
        pmos_row1.value(1)  # Turn on PMOS for row 1
        pmos_row2.value(0)  # Turn off PMOS for row 2
        pmos_row3.value(0)  # Turn off PMOS for row 3
    elif index < 26:
        pmos_row1.value(0)  # Turn off PMOS for row 1
        pmos_row2.value(1)  # Turn on PMOS for row 2
        pmos_row3.value(0)  # Turn off PMOS for row 3
    else:
        pmos_row1.value(0)  # Turn off PMOS for row 1
        pmos_row2.value(0)  # Turn off PMOS for row 2
        pmos_row3.value(1)  # Turn on PMOS for row 3

    # Set the correct channel to '1' to turn on the desired LED
    outputs[channel] = '1'

    # Convert outputs list to string
    outputs_str = ''.join(outputs)
    byte_array = simple_byte_array(outputs_str)
    tlc.set_data(byte_array)

def play_or_stop_song(button, song):
    """
    Play or stop a song based on the pressed button.
    """
    global current_button, current_song

    if current_button == button:
        wp.stop()
        clear_display()
        current_button = None
        current_song = None
    else:
        if current_button is not None:
            wp.stop()
        clear_display()
        display_text_centered([song[:-4].replace("_", " ")])
        wp.play(song, loop=False)
        current_button = button
        current_song = song

def display_text_centered(lines):
    """
    Display given lines of text centered on the OLED display.
    """
    oled.fill(0)
    line_height = 8
    actual_lines = []

    for line in lines:
        # Split lines longer than 16 characters
        if len(line) > 16:
            middle = len(line) // 2
            left = middle
            right = middle + 1

            # Search for spaces near the middle to find a good split point
            while left > 0 and line[left] != ' ':
                left -= 1
            while right < len(line) and line[right] != ' ':
                right += 1

            if (middle - left) <= (right - middle) and left > 0:
                split_point = left
            elif right < len(line):
                split_point = right
            else:
                split_point = middle  # Fallback to middle if no spaces found

            first_half = line[:split_point].strip()
            second_half = line[split_point:].strip()
            actual_lines.append(first_half)
            actual_lines.append(second_half)
        else:
            actual_lines.append(line)

    total_lines = len(actual_lines)
    total_height = total_lines * line_height
    y_start = (oled.height - total_height) // 2

    for i, line in enumerate(actual_lines):
        x = (oled.width - len(line) * 8) // 2
        y = y_start + i * line_height
        oled.text(line, x, y)

    oled.show()

def clear_display():
    """
    Clear the OLED display.
    """
    global current_button, current_song

    oled.fill(0)
    oled.show()
    current_button = None
    current_song = None

def display_go_gators():
    """
    Display "Go Gators!" on the OLED, scrolling horizontally. The text will pause for 5 seconds when it is centered.
    """
    global text_x_offset, text_scroll_speed, text_last_update, text_paused, text_pause_start, text_pause_duration

    # Calculate the center position for the text to pause
    text_width = len(go_gators_text) * 8
    center_position = (128 - text_width) // 2

    current_time = time.ticks_ms()

    # If the text is not paused, move it horizontally
    if not text_paused:
        # Check if it's time to update the text position
        if time.ticks_diff(current_time, text_last_update) > text_update_interval:
            text_last_update = current_time
            # Move the text horizontally
            text_x_offset += text_scroll_speed

            # If the text has reached the center position, start the pause
            if center_position <= text_x_offset < center_position + text_scroll_speed:
                text_x_offset = center_position  # Ensure it exactly matches the center
                text_paused = True
                text_pause_start = current_time
    else:
        # If the text is paused, check if the pause duration has elapsed
        if time.ticks_diff(current_time, text_pause_start) > text_pause_duration:
            text_paused = False
            text_last_update = current_time  # Reset update time to avoid skipping a step
            # Increment text_x_offset to resume scrolling from the center
            text_x_offset += text_scroll_speed

    # If the text has scrolled completely to the right of the screen, reset it to the left
    # This condition ensures continuous scrolling cycle
    if text_x_offset > 128:
        text_x_offset = -text_width
        text_paused = False  # Ensure not paused at start

    # Clear the display and draw the text at the current offset
    oled.fill(0)
    oled.text(go_gators_text, text_x_offset, (oled.height - 8) // 2)  # Center vertically
    oled.show()

# Variables to keep track of the currently pressed button and song
current_button = None
current_song = None

while True:
    current_time = time.ticks_ms()

    # Handle song buttons
    for button, song in button_songs.items():
        if not button.value():  # If button is pressed
            # Debounce check
            if time.ticks_diff(current_time, last_button_press) > debounce_delay:
                play_or_stop_song(button, song)
                last_button_press = current_time

    # Check if the WAV player is still playing
    if current_button is not None and not wp.isplaying():
        clear_display()
        current_button = None
        current_song = None

    # Handle Button_4 for LED cycling
    if not Button_4.value() and time.ticks_diff(current_time, last_button_press) > debounce_delay:
        cycling = not cycling  # Toggle cycling state
        last_button_press = current_time  # Update last button press time

        # Turn off all LEDs if cycling is disabled
        if not cycling:
            pmos_row1.value(0)
            pmos_row2.value(0)
            pmos_row3.value(0)
            outputs = ['0'] * 16
            tlc.set_data(simple_byte_array(''.join(outputs)))

            # Only clear display if no music is playing
            if current_song is None:
                clear_display()
        else:
            # If cycling was just turned on and music is playing, display the current song
            if current_song is not None:
                display_text_centered([current_song[:-4].replace("_", " ")])

    # Handle LED cycling
    if cycling:
        if time.ticks_diff(current_time, last_led_update) > led_update_interval:
            turn_on_leds(led_index)  # Turn on the current LED
            led_index = (led_index + 1) % 39  # Move to the next LED
            last_led_update = current_time  # Update last LED update time

        # If no music is playing and LEDs are on, display "Go Gators!"
        if current_song is None:
            display_go_gators()

    time.sleep(0.05)
